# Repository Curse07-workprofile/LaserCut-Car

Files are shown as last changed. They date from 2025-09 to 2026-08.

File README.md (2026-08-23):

# CAD Laser-Cut Car Project  

This is a **Laser-cut Cardboard Car** that was designed to demonstrate 3D CAD modelling skills and creativity.  
Needed to be cut from one A3 sheet of cardboard and be assembled to be free standing. 
The project succeeded in these objectives.

### Contents  

- [Photos](./Photos/photos.md) - Images of the completed model (click here to see all photos)
- [CAD Assemblies](./Model+Cut_Files/assembly(s)/) - CAD assembly files (SolidWorks assembly files)
- [CAD Parts](./Model+Cut_Files/parts/) - CAD part files (SolidWorks part files)
- [Lasercut File](./Model+Cut_Files/Lasercutting_Flat.DXF) - DXF file to be loaded onto cutter

### Tools Used  

- SolidWorks (CAD design)  
- Laser cutting (fabrication). CO2 laser. Kerf width of aproximatly 0.25mm for 1.3mm card.  

### Preview  

---
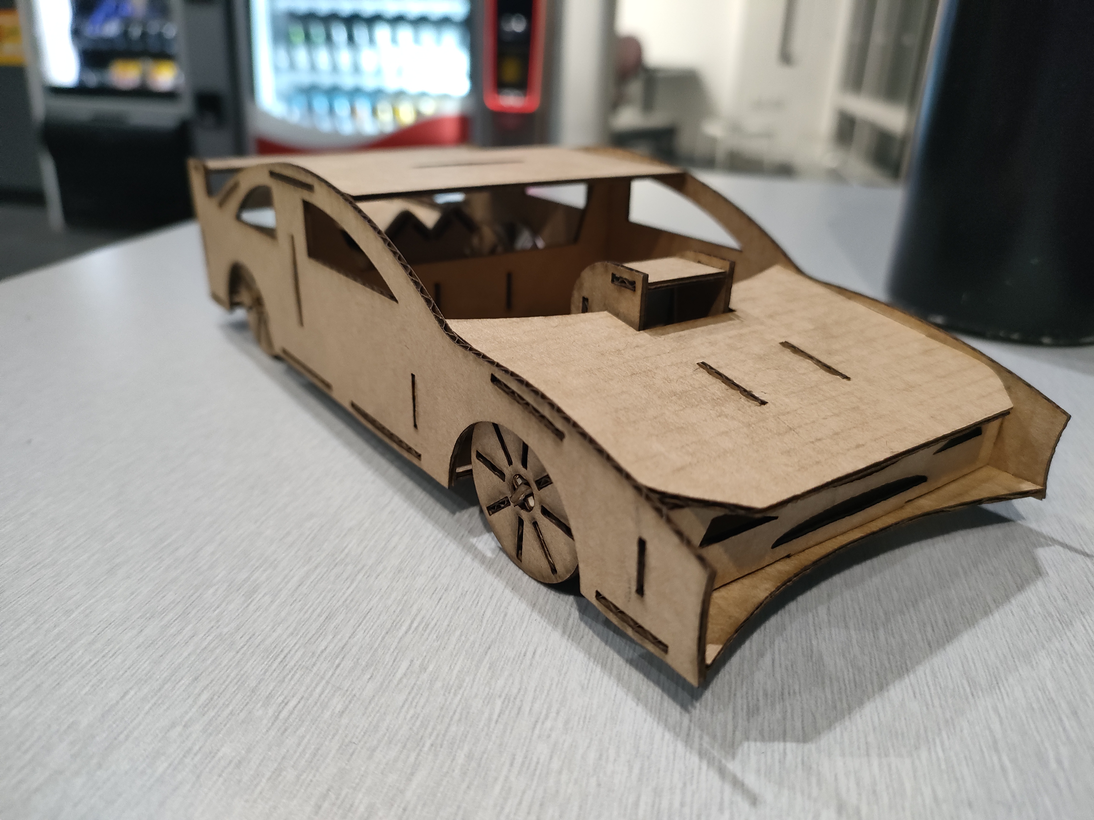
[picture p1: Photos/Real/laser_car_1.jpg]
  
---

### Modelling

The modelling was quite simple as it only included flat shape feature extruded to the thickness of the card itself.
Where the challenge lay was in the assembly and the accomodation of the kerf width tolerances considerations for the actual assembly.
This requrire a number of iterations and adjustments to get correct; Especially the angle of the bonnet and that scoop and the wheel seating height.
For clarity this is not a realistic design as the engine is located in the back while there is a scoop/intake thing through the bonnet.
But it looks awesome and I'm a mechatronics major; mechanical sins of infeasibility don't faze me. 
**To all potential employers that is a JOKE; It utilizes quantum tunneling to force air to the lone engine block, which doesn't need anything else to provide full vechical functionality.**
Shown below is a photo of the CAD assembly from Solidworks:

---
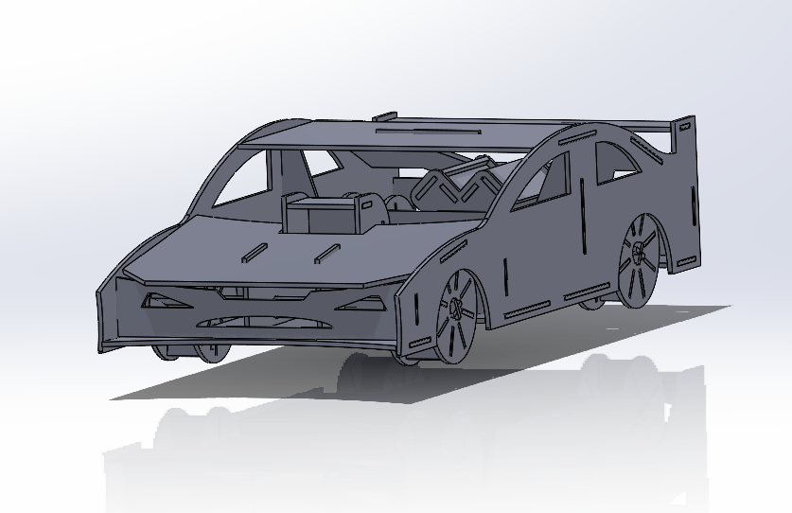
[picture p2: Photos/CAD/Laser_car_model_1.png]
  
---

See more photos in the Photos link from contents section.

### Laser Cutting

The Laser cutting involve taking every part of the assmebly and laying them flat on a plane to then generate the .DXF file.
This is linked to by the Lasercut file in the contents section.
This file is made to hold every part inside of the equivalent of an A3 section.
This is designed for a C02 laser with the aforemeationed kerf width.
One consideration when cutting: the axels part that slot together are on the thinner side and due to card inperfections spares of these should be printed.
This control can be done easily at the printer before printing.

### Physical Construction 

This does take a while to put together because of the number of parts.
Also depending on card imperfections it may be advantagous to have a pen to widen or push-together slots and fins respectively.
It does assemble together quite rigidly inspite of these considerations, and still holds up even a year later.

### Post Thoughts

This was a very open free project that didn't require this level of effort or complexity, however, I was inspired to challenge myself. 
It did seem like a gamble right upto the point I was able to put it together.
But I think this allowed me to build confidence in my ability to make calculations and estimations, aswell as build my intuition for what works going from concept to product. 

---
*Developed as a part of a university project*

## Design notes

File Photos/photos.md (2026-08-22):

# Pictures of the Car

## Real Photos of Finished Product

### Front
Finished Car 1

### Side
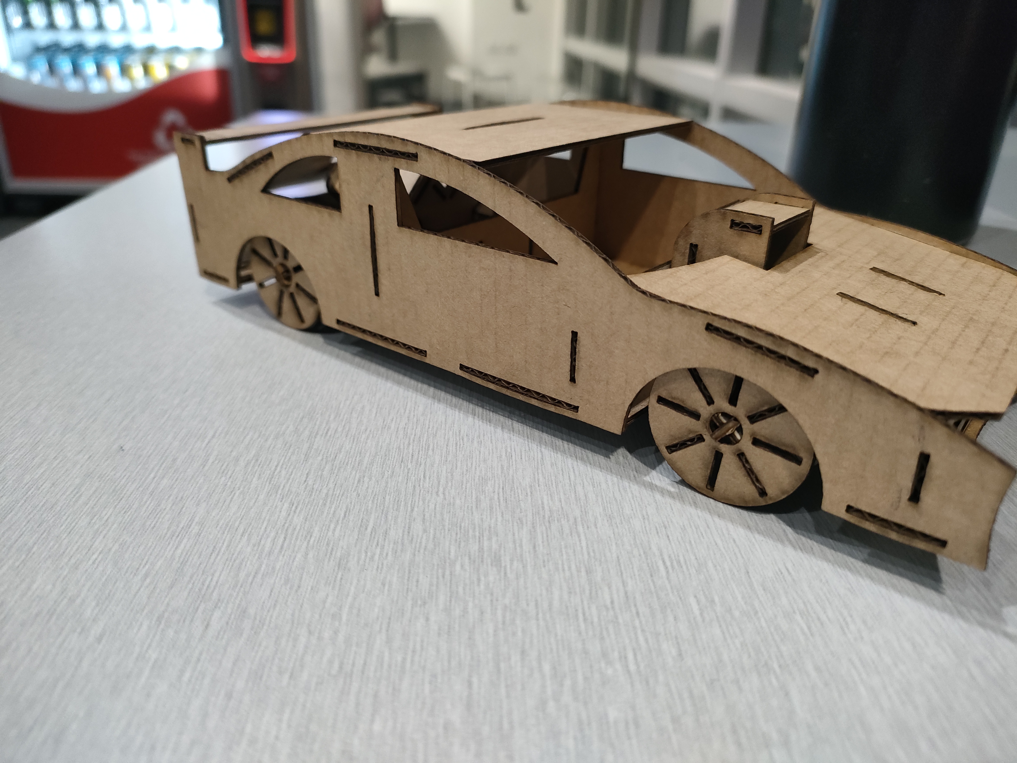
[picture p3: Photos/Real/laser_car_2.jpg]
Finished Car 2


### Angular
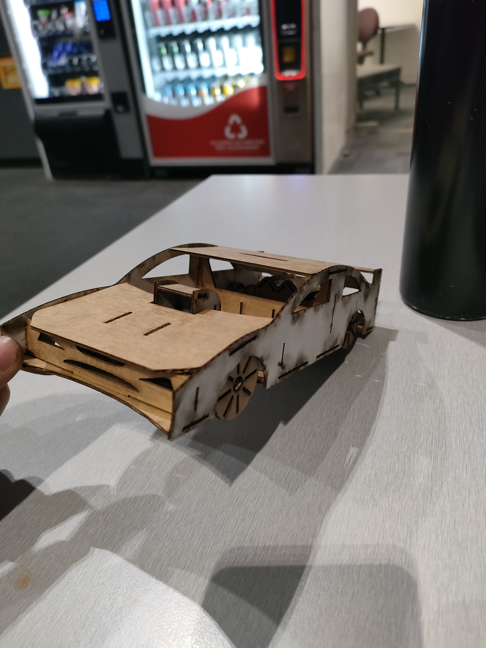
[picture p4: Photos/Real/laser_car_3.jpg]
Finished Car 3


### Back
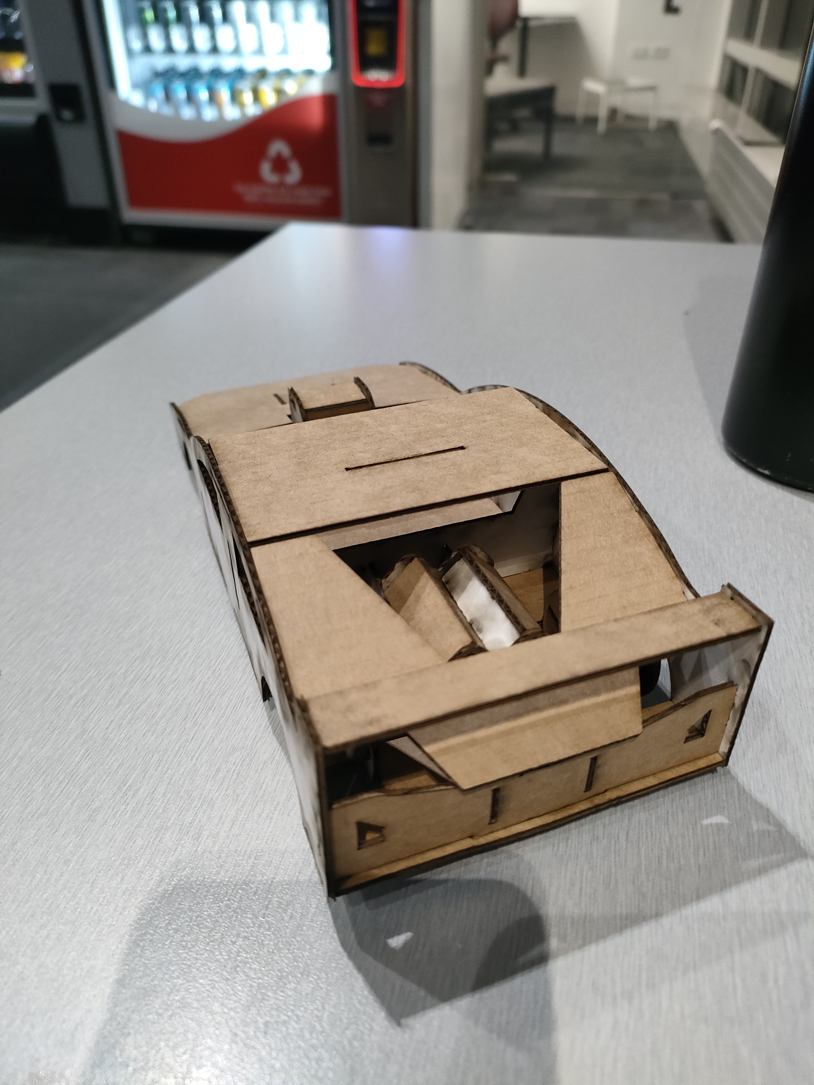
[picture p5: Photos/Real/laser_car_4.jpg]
Finished Car 4


## Photos of CAD design Assembly in SolidWorks

### Front
CAD Car 1

### Back
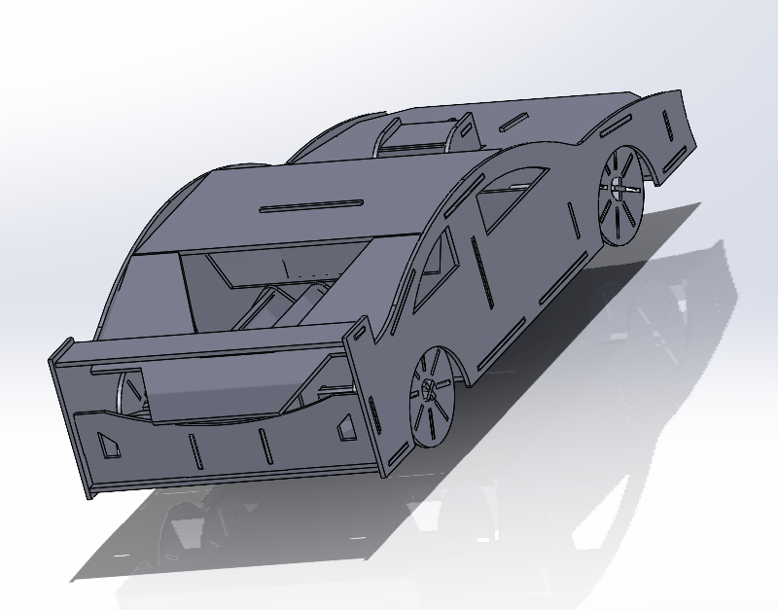
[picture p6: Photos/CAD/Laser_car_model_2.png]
CAD Car 2


### Side
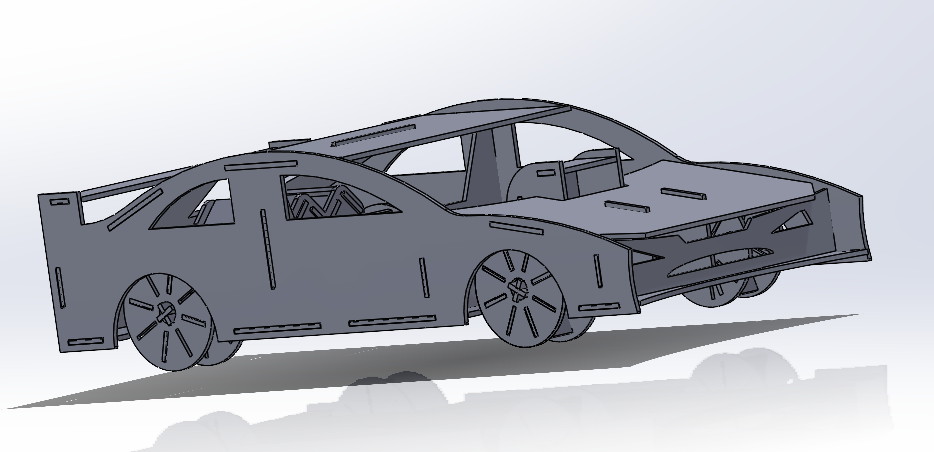
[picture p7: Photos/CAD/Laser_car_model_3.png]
CAD Car 3


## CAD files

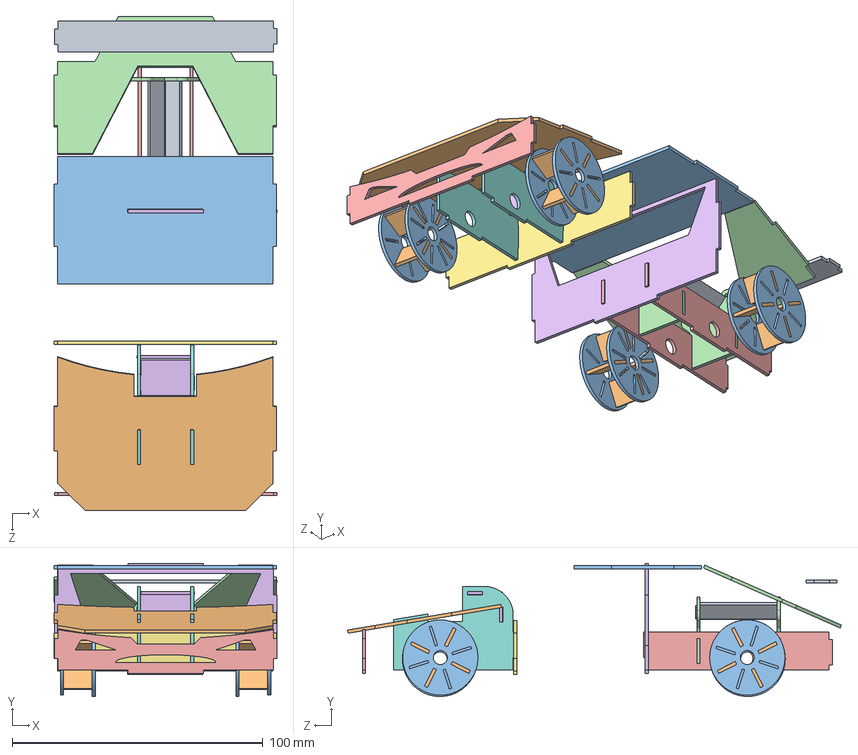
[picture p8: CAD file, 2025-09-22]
Model+Cut_Files/assembly(s)/Proper_car_assem.SLDASM
88.9 x 53.0 x 196.9 mm
middle_part_draft
front_grill_draft
rear_top_part_draft
roof_plate
bonnet_draft
wing_draft
super_charger_draft x 2
steering_support_draft
super_charger_cap_draft x 2
Engine_bracket x 2
Engine_ends_draft x 2
wheel_draft x 9
wheel_spoke_draft x 16
Engine_joint2_draft x 2

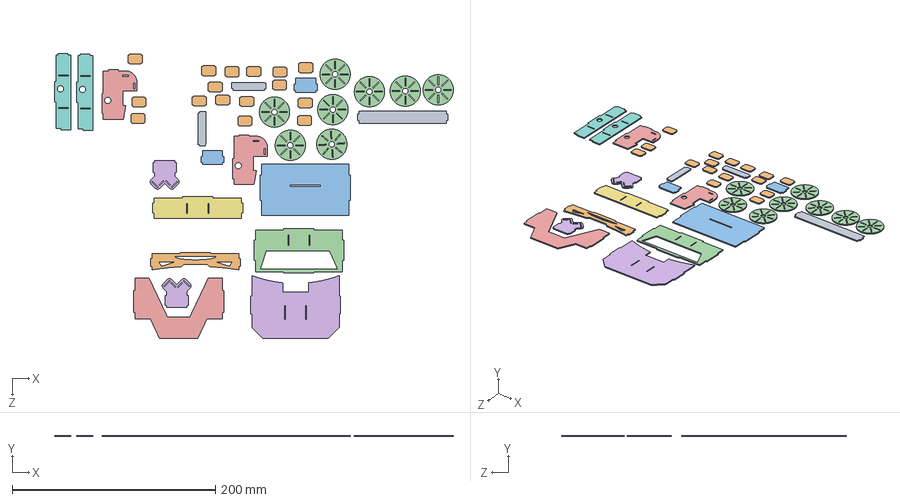
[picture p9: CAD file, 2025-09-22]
Model+Cut_Files/assembly(s)/cutting_work_assem.SLDASM
392.3 x 1.30 x 280.5 mm
bonnet_draft
rear_top_part_draft
middle_part_draft
roof_plate
front_grill_draft
wing_draft
Engine_bracket x 2
steering_support_draft
Engine_ends_draft x 2
super_charger_draft x 2
wheel_draft x 8
super_charger_cap_draft x 2
wheel_spoke_draft x 16
Engine_joint2_draft x 2

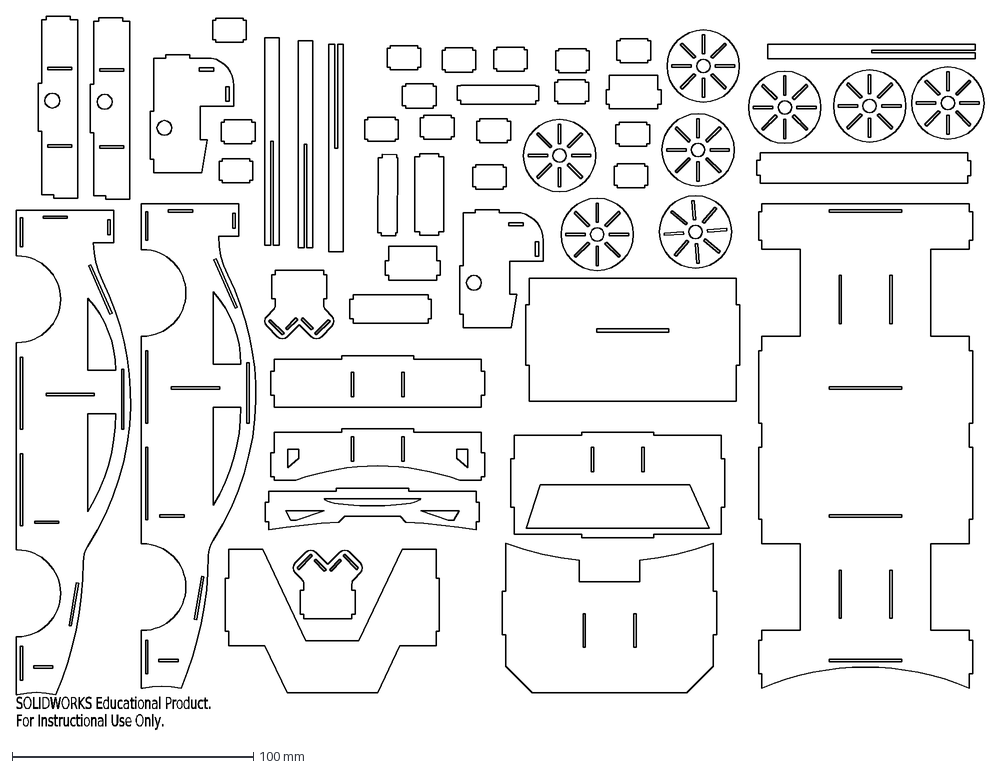
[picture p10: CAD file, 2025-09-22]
Model+Cut_Files/Lasercutting_Flat.DXF
SOLIDWORKS Educational Product.
For Instructional Use Only.

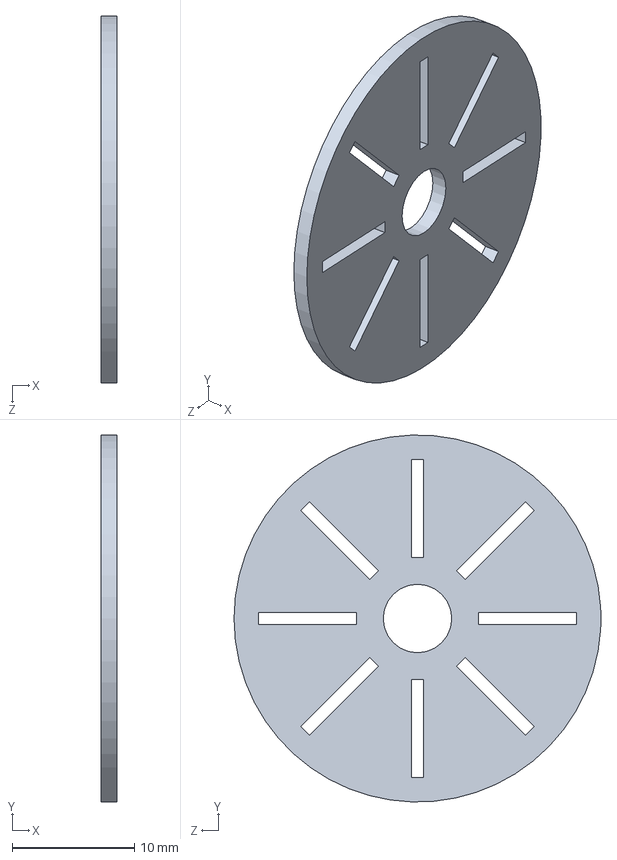
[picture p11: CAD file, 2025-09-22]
Model+Cut_Files/parts/wheel_draft.SLDPRT
1.30 x 30.0 x 30.0 mm

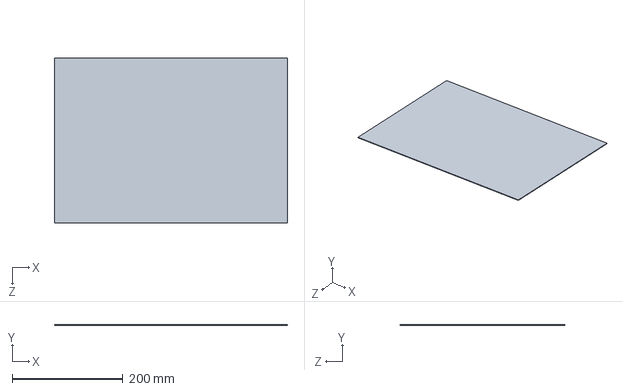
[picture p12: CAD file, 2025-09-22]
Model+Cut_Files/cut_sheet.SLDPRT
420.0 x 1.30 x 297.0 mm

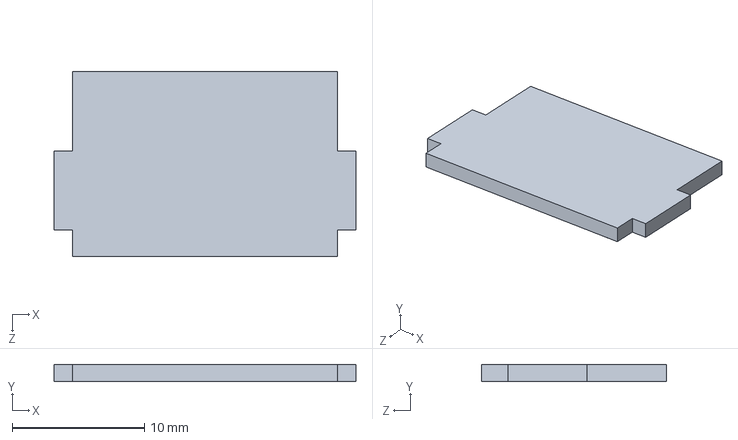
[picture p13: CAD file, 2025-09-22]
Model+Cut_Files/parts/super_charger_cap_draft.SLDPRT
22.8 x 1.30 x 14.0 mm

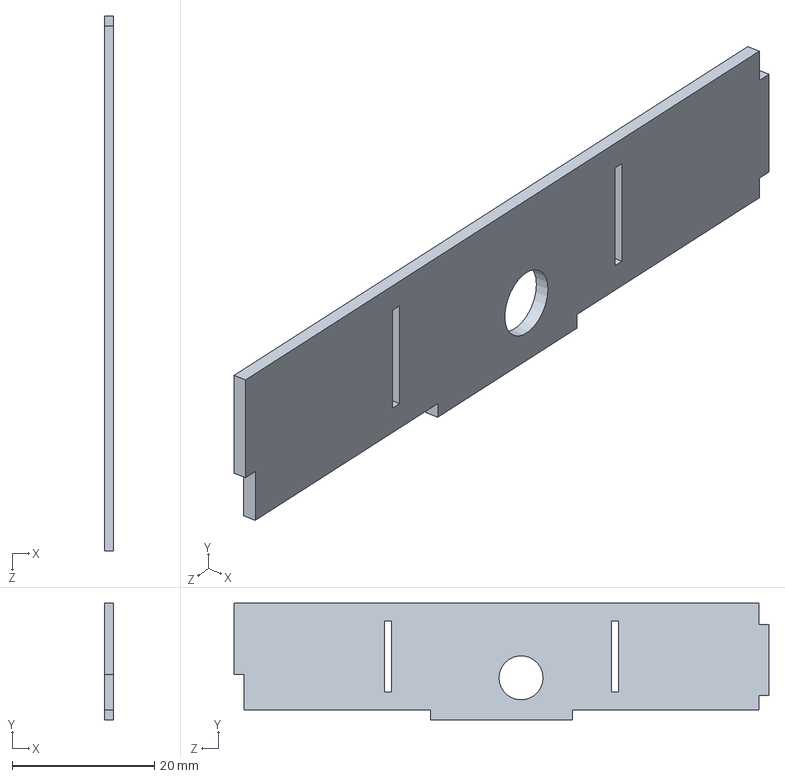
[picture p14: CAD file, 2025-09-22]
Model+Cut_Files/parts/Engine_bracket.SLDPRT
1.30 x 16.4 x 75.3 mm

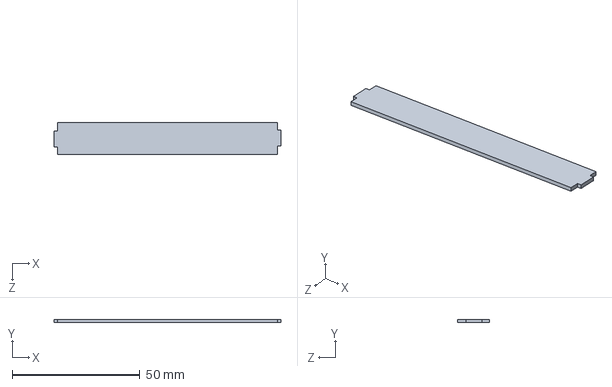
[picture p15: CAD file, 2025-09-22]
Model+Cut_Files/parts/wing_draft.SLDPRT
88.8 x 1.30 x 12.5 mm

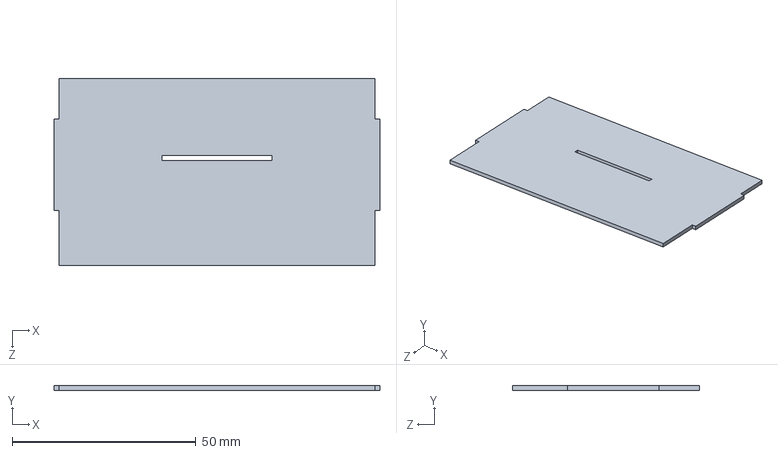
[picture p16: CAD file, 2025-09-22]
Model+Cut_Files/parts/roof_plate.SLDPRT
88.8 x 1.30 x 51.0 mm

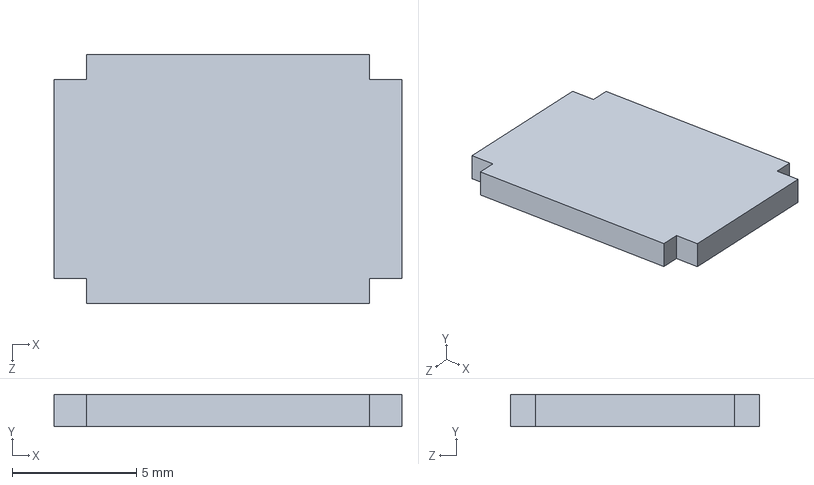
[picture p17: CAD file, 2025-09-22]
Model+Cut_Files/parts/wheel_spoke_draft.SLDPRT
14.0 x 1.30 x 10.0 mm

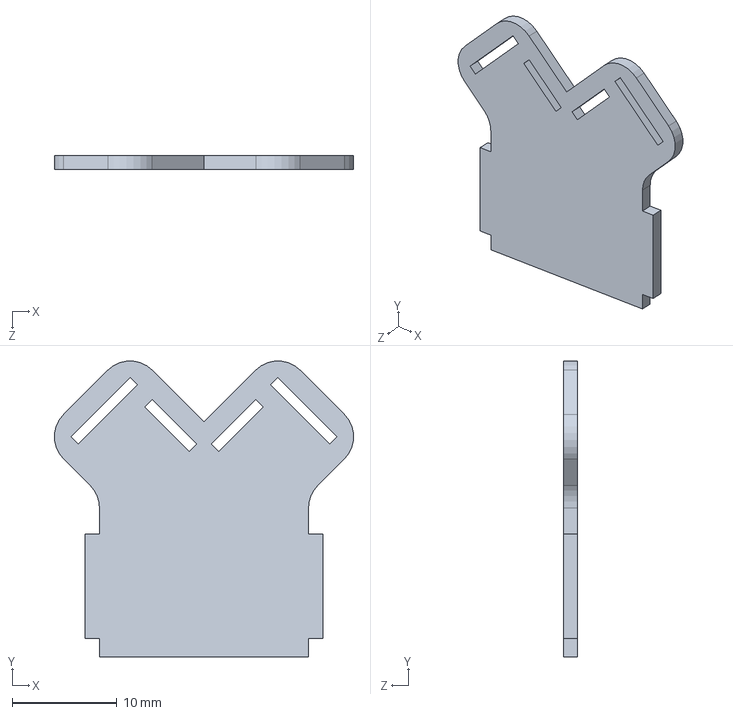
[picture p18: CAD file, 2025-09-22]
Model+Cut_Files/parts/Engine_ends_draft.SLDPRT
28.6 x 28.3 x 1.30 mm

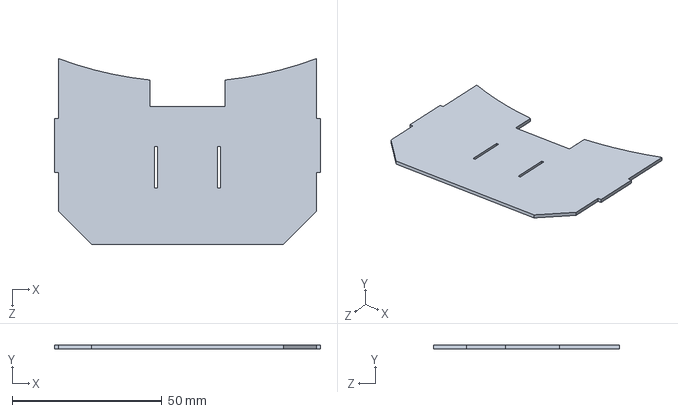
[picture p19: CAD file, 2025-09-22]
Model+Cut_Files/parts/bonnet_draft.SLDPRT
88.8 x 1.30 x 62.0 mm

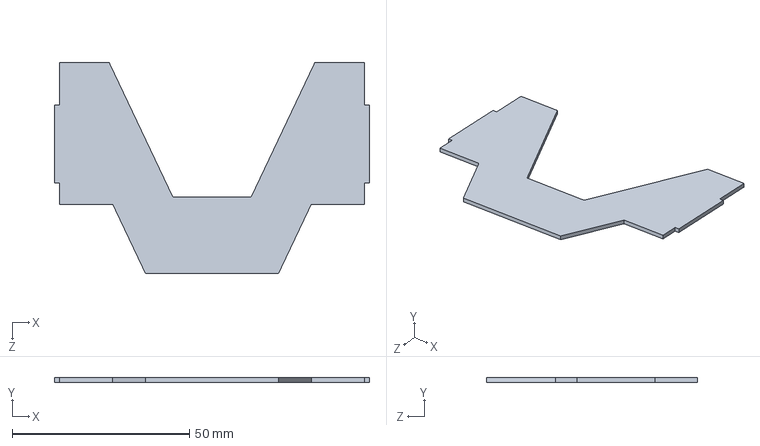
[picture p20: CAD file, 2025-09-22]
Model+Cut_Files/parts/rear_top_part_draft.SLDPRT
88.8 x 1.30 x 59.5 mm

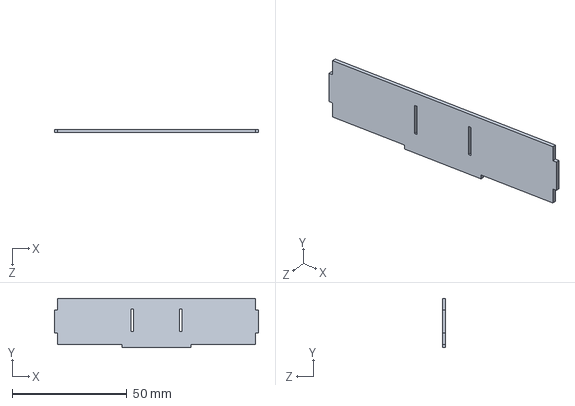
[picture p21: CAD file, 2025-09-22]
Model+Cut_Files/parts/steering_support_draft.SLDPRT
88.8 x 21.4 x 1.30 mm

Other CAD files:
Model+Cut_Files/parts/front_grill_draft.SLDPRT
Model+Cut_Files/parts/middle_part_draft.SLDPRT
Model+Cut_Files/parts/super_charger_draft.SLDPRT
Model+Cut_Files/parts/Engine_joint2_draft.SLDPRT
Model+Cut_Files/parts/Engine_joint_draft.SLDPRT
Model+Cut_Files/parts/back_plate_draft.SLDPRT
Model+Cut_Files/parts/base_plate_draft.SLDPRT
Model+Cut_Files/parts/draft_axel.SLDPRT
Model+Cut_Files/parts/side_part_draft.SLDPRT

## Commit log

2026-08-22 Add real photos and CAD design images to documentation
2026-08-23 Revise README for CAD Laser-Cut Car Project
    Updated project title and improved text clarity. Added sections on modelling, laser cutting, physical construction, and post thoughts.
